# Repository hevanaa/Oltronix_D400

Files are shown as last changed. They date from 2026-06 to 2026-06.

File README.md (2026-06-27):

# Oltronix D400-007D Regulator Board (KiCad redesign)

This repository contains a redesigned regulator board for the Oltronix D400-007D 400 V DC power supply.

The goal of this redesign is improved safety margins, better component availability, and improved PCB high-voltage layout compared to the original design.

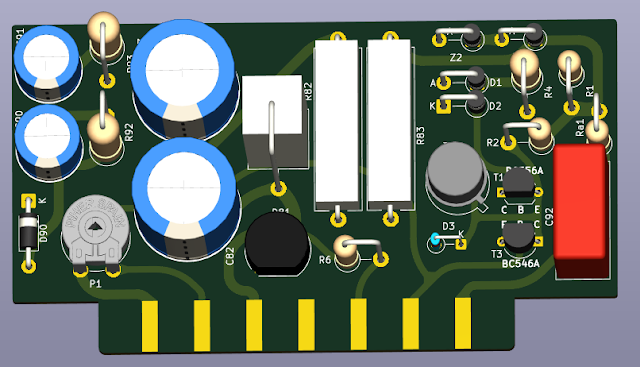
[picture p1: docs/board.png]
PCB


---

## Project structure

- `/project/`  
  KiCad PCB and schematic files

- `/production/`  
  Gerber files, drill files

- `/docs/`  
  Documentation, and reference material

- `/bom/`  
  Bill of Materials (CSV / spreadsheet format)

---

## Design overview

This board replaces the original regulator / error amplifier section of the power supply.

Key improvements include:
- Increased high-voltage clearance in critical areas
- Improved creepage distance at edge connector
- Use of modern, readily available components
- Slight circuit refinements for reliability (e.g. protection diode on driver stage)

---

## PCB design notes

### Edge connector safety improvement

The original design used a single-sided PCB edge connector layout, resulting in insufficient clearance between high-voltage pins (notably 220 V AC input and ~320–360 V DC rail).

This redesign uses a **double-sided alternating pad layout**, where connector contacts are split between top and bottom layers.

This achieves:
- Significantly increased creepage distance (>5 mm effective)
- Reduced risk of carbon tracking and flashover
- Improved robustness under contamination and aging

Pad geometry was also adjusted to better match connector cavity dimensions.

---

## Component labeling convention

This project follows the original Oltronix reference designators where possible.

- **T1, T2, T3** → Transistors  
- **D1, D2, D3** → Diodes  
- **Rxx** → Resistors (high-voltage / power-rated where specified)  
- **Cxx** → Capacitors  
- **P1** → Adjustment potentiometer / calibration trimmer  

When deviations from the original design exist, they are documented in the schematic notes.

---

## Manufacturing notes

- Standard 1.6 mm FR-4 PCB thickness assumed
- High-voltage areas require clean routing and no solder mask contamination in critical creepage zones
- Some resistors must withstand elevated voltage stress and should not be substituted with generic low-voltage types

---

## Adjustments

P1 must be adjusted during commissioning as described in the accompanying blog article:
https://baldpenguin.blogspot.com/2026/04/another-oltronix-power-supply-d400-007d.html

---

## External documentation

Detailed design rationale, repair notes, and BOM information are documented in accompanying articles:

- Part 1 (design analysis and failure modes):  
  https://baldpenguin.blogspot.com/2026/04/another-oltronix-power-supply-d400-007d.html

- Part 2 (repair implementation and BOM details):  
  https://baldpenguin.blogspot.com/2026/06/repairing-oltronix-d400-007d-part-2.html

Part 2 contains practical component substitutions and ordering examples.

---

## License

This repository contains a redesigned replacement for the regulator board used in the Oltronix D400-007D power supply.

The original device and schematic are the property of their respective rights holders and are not included under this license.

This project covers only the original work created in this repository, including the PCB layout, modified schematic, BOM, and documentation.

This project is licensed under the CERN-OHL-S v2 (Strongly Reciprocal).

See `LICENSE` file for details.

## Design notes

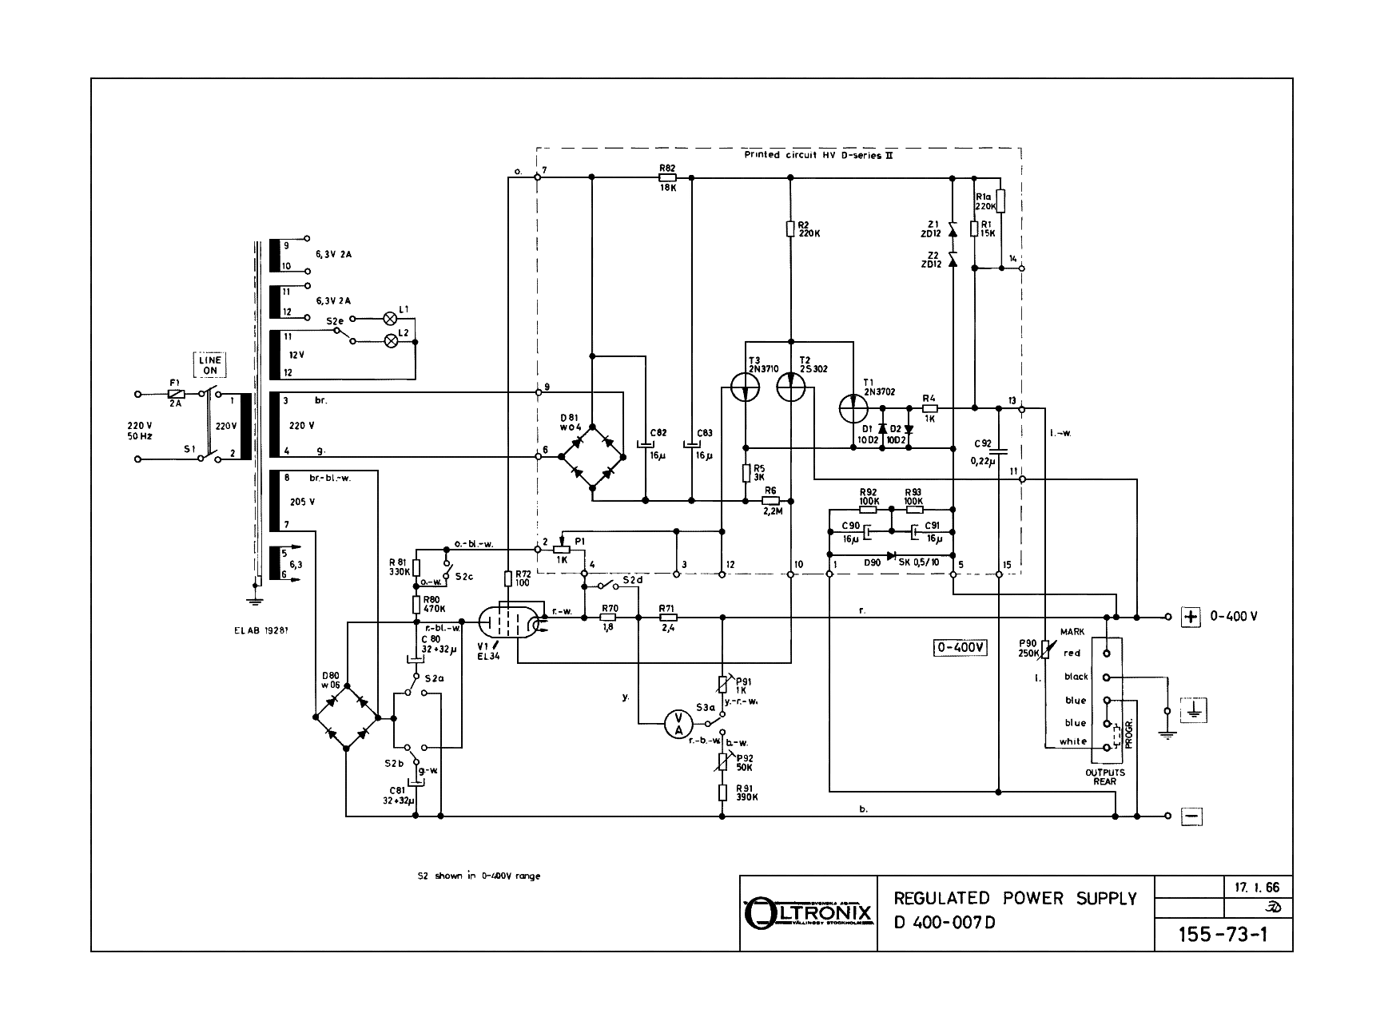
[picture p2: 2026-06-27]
docs/Oltronix_D40-04d_d400-007d_psu-serie_1966_sm-001.png

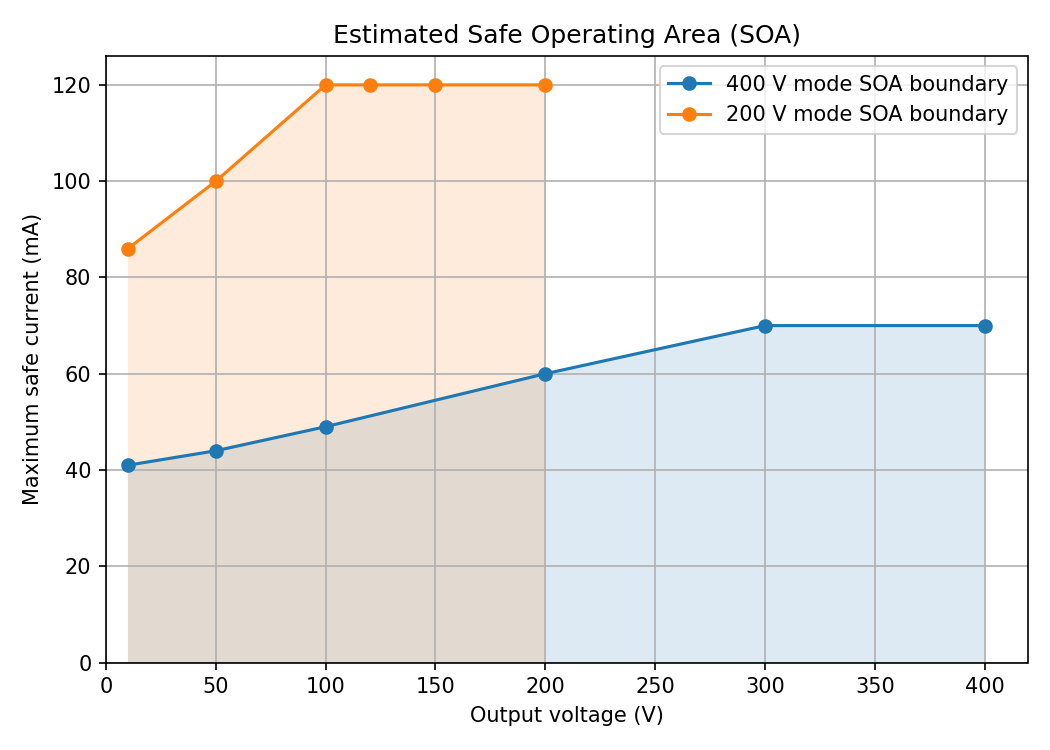
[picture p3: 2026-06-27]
docs/EL34_SOA_voltage_current.png

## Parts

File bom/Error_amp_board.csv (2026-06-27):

Reference | Value | Datasheet | Footprint | Qty | DNP
C82,C83,C90,C91 | 22µF |  | Capacitor_THT:CP_Radial_D10.0mm_P5.00mm,Capacitor_THT:CP_Radial_D16.0mm_P7.50mm | 4
C92 | 0.22 µF |  | Capacitor_THT:C_Rect_L18.0mm_W8.0mm_P15.00mm_FKS3_FKP3 | 1
D1,D2,D90 | 1N4007 | http://www.vishay.com/docs/88503/1n4001.pdf | Diode_THT:D_DO-41_SOD81_P10.16mm_Horizontal,Diode_THT:D_DO-41_SOD81_P5.08mm_Vertical_AnodeUp,Diode_THT:D_DO-41_SOD81_P5.08mm_Vertical_CathodeUp | 3
D3 | 1N4148 | https://assets.nexperia.com/documents/data-sheet/1N4148_1N4448.pdf | Diode_THT:D_DO-35_SOD27_P3.81mm_Vertical_CathodeUp | 1
D81 | W10G | https://www.vishay.com/docs/88769/woo5g.pdf | Diode_THT:Diode_Bridge_Round_D9.8mm | 1
J1 | Edge connector |  | johanh-footprints:Oltronix_HV_board_edge_connector_15 | 1
P1,R4 | 1k |  | Potentiometer_THT:Potentiometer_Piher_PT-10-V10_Vertical,Resistor_THT:R_Axial_DIN0414_L11.9mm_D4.5mm_P5.08mm_Vertical | 2
R1 | 15k |  | Resistor_THT:R_Axial_DIN0411_L9.9mm_D3.6mm_P5.08mm_Vertical | 1
R2,Ra1 | 220k |  | Resistor_THT:R_Axial_DIN0411_L9.9mm_D3.6mm_P5.08mm_Vertical | 2
R5 | 3k |  | Resistor_THT:R_Axial_Power_L25.0mm_W9.0mm_P7.62mm_Vertical | 1
R6 | 2.2M |  | Resistor_THT:R_Axial_DIN0411_L9.9mm_D3.6mm_P5.08mm_Vertical | 1
R82,R83 | 9k |  | johanh-footprints:R_Axial_Power_L25.4mm_W7mm_P27.94mm | 2
R92,R93 | 100k |  | Resistor_THT:R_Axial_DIN0516_L15.5mm_D5.0mm_P5.08mm_Vertical | 2
T1 | BC556A | https://www.onsemi.com/pub/Collateral/BC556BTA-D.pdf | Package_TO_SOT_THT:TO-92_Inline_Wide | 1
T2 | 2N4037 |  | Package_TO_SOT_THT:TO-39-3 | 1
T3 | BC546A | https://www.onsemi.com/pub/Collateral/BC550-D.pdf | Package_TO_SOT_THT:TO-92_Inline_Wide | 1
Z1,Z2 | BZX85C12 | https://www.vishay.com/docs/85816/1n4728a.pdf | Diode_THT:D_DO-41_SOD81_P5.08mm_Vertical_AnodeUp | 2

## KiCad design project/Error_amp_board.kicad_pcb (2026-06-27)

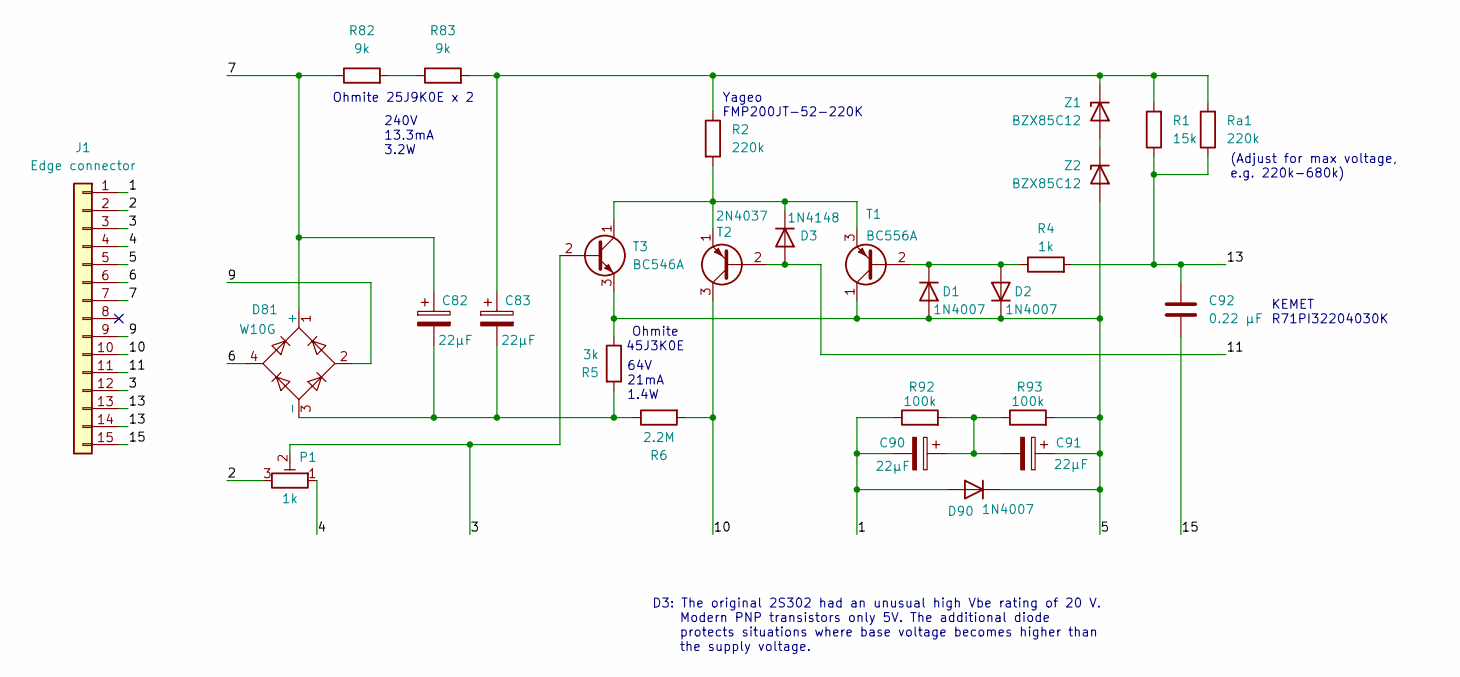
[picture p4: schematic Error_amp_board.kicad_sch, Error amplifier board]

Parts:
C82, C83: 22µF; CP_Radial_D16.0mm_P7.50mm
C90, C91: 22µF; CP_Radial_D10.0mm_P5.00mm
C92: 0.22 µF; C_Rect_L18.0mm_W8.0mm_P15.00mm_FKS3_FKP3
D1: 1N4007; D_DO-41_SOD81_P5.08mm_Vertical_AnodeUp
D2: 1N4007; D_DO-41_SOD81_P5.08mm_Vertical_CathodeUp
D3: 1N4148; D_DO-35_SOD27_P3.81mm_Vertical_CathodeUp
D81: W10G; Diode_Bridge_Round_D9.8mm
D90: 1N4007; D_DO-41_SOD81_P10.16mm_Horizontal
J1: Edge connector; Oltronix_HV_board_edge_connector_15
P1: 1k; Potentiometer_Piher_PT-10-V10_Vertical
R1: 15k; R_Axial_DIN0411_L9.9mm_D3.6mm_P5.08mm_Vertical
R2: 220k; R_Axial_DIN0411_L9.9mm_D3.6mm_P5.08mm_Vertical
R4: 1k; R_Axial_DIN0414_L11.9mm_D4.5mm_P5.08mm_Vertical
R5: 3k; R_Axial_Power_L25.0mm_W9.0mm_P7.62mm_Vertical
R6: 2.2M; R_Axial_DIN0411_L9.9mm_D3.6mm_P5.08mm_Vertical
R82, R83: 9k; R_Axial_Power_L25.4mm_W7mm_P27.94mm
R92, R93: 100k; R_Axial_DIN0516_L15.5mm_D5.0mm_P5.08mm_Vertical
Ra1: 220k; R_Axial_DIN0411_L9.9mm_D3.6mm_P5.08mm_Vertical
T1: BC556A; TO-92_Inline_Wide
T2: 2N4037; TO-39-3
T3: BC546A; TO-92_Inline_Wide
Z1, Z2: BZX85C12; D_DO-41_SOD81_P5.08mm_Vertical_AnodeUp

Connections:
/1: C90.2, D90.2 (A), J1.1, R92.1
/2: J1.2, P1.3
/3: J1.3, J1.12, P1.2, T3.2 (B)
/4: J1.4, P1.1
/5: C91.1, D1.2 (A), D2.1 (K), D90.1 (K), J1.5, R5.1, R93.2, T1.1 (C), T3.3 (E), Z2.2 (A)
/6: D81.4, J1.6
/7: C82.1, D81.1 (+), J1.7, R82.1
/9: D81.2, J1.9
/10: J1.10, R6.2, T2.3 (C)
/11: D3.2 (A), J1.11, T2.2 (B)
/13: C92.1, J1.13, J1.14, R1.1, R4.2, Ra1.1
/15: C92.2, J1.15
unnamed: C90.1, C91.2, R92.2, R93.1
unnamed: D1.1 (K), D2.2 (A), R4.1, T1.2 (B)
unnamed: D3.1 (K), R2.2, T1.3 (E), T2.1 (E), T3.1 (C)
unnamed: C82.2, C83.2, D81.3 (-), R5.2, R6.1
unnamed: R82.2, R83.1
unnamed: Z1.2 (A), Z2.1 (K)
unnamed: C83.1, R1.2, R2.1, R83.2, Ra1.2, Z1.1 (K)

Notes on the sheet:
KEMET R71PI32204030K
Ohmite 45J3K0E
D3: The original 2S302 had an unusual high Vbe rating of 20 V. Modern PNP transistors only 5V. The additional diode protects situations where base voltage becomes higher than the supply voltage.
Yageo FMP200JT-52-220K
240V 13.3mA 3.2W
64V 21mA 1.4W
Ohmite 25J9K0E x 2
(Adjust for max voltage, e.g. 220k-680k)

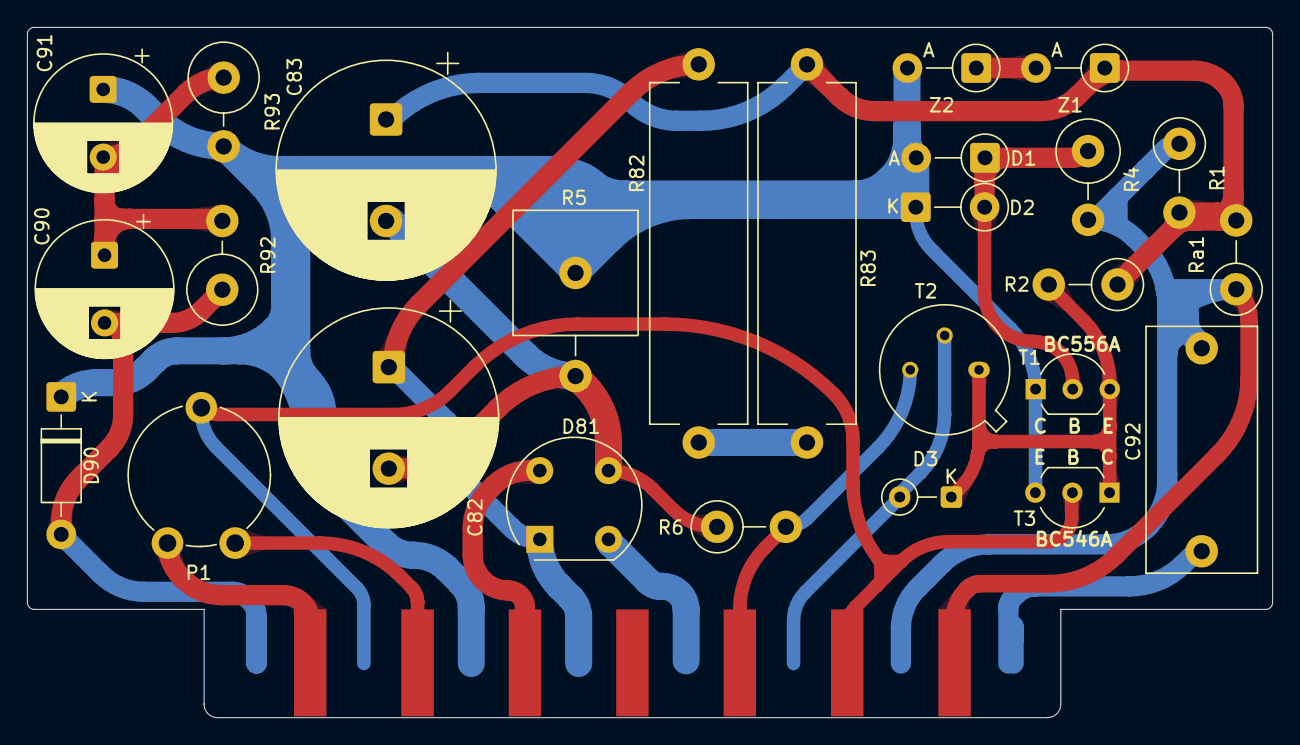
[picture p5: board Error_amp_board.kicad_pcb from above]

Board: 2 copper layers, 92.0 x 51.0 mm, 27 parts (1 on the bottom side), 19 nets.

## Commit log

2026-06-27 added bom
    [Error_amp_board.csv]
2026-06-27 added board picture
